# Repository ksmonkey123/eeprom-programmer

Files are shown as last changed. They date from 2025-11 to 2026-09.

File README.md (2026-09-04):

EEPROM Programmer
=================

Arduino-based EEPROM programmer for the AT28C64B (8 KiB) and AT28C256 (32 KiB) EEPROMs.

## Design

The EEPROM programmer consists of 2 parts:
A _Programmer Device_ based consiting of an Arduino Mega 2560 with a daughter-board containing an IC socket for the
EEPROM chips (DIP-28P6).
This _Programmer Device_ interacts with a _Client Program_ on the PC.

## Features

### Software Data Protection

The programmer supports enabling and disabling of the _Software Data Protection_ (Write Lockout) mode on the EEPROM.
This feature can be used as a standalone command (`<cmd> lock` and `<cmd> unlock`), and in combination with other _write
operations_.
It is even possible to unlock an EEPROM, write to it, and lock it again in a single operation.

### Automatic EEPROM size determination

Since the programmer supports 2 different sizes of EEPROMs, the user would have to indicate what type is connected to
the programmer for any given command.
The _Client Program_ is, however, capable of "guessing" the safe EEPROM size for most operations.
In some cases this may lead to additional unnecessary write cycles on smaller chips (which we consider to be a
negligible downside) and potentially increased operation durations.

The following pseudo-C shows the test routine to definitely determine the EEPROM size.
This test can be performed both destructively and non-desctructively.
In all cases the EEPROM _must_ be unlocked beforehand.

```c
bool isLargeChip(bool preserveData) {
  address adr = random(0x0000, 0x2000);
  byte data = read(adr);

  // if there's different data in the higher "blocks", it obviously is a large chip
  if (data != read(adr + 0x2000)) {
    return true;
  }

  // modify low byte, check if high byte changes too
  write(adr, ~data);
  //high byte unchanged means large chip
  bool result = (data == read(adr + 0x2000));

  if (preserveData) {
    write(adr, data);
  }
  return result;
}
```

### Considerate Writes

Unnecessary Write operations are avoided whenever possible. 
This means that the programmer will not write to a byte if the new value is the same as the old one.
This reduces both write times and wear on the EEPROM.

## Operations

### Erase

The `erase` opration writes `0xFF` to every byte of the EEPROM memory.
When an explicit size flag is set, the corresponding deletion logic is performed.
Otherwise, we perform a destructive _size test_ before flashing the EEPROM.

### Dump

The `dump` command reads the entire contents of the EEPROM.
If a size is specified, the output file has the matching size.
If no size is specified, the EEPROM is read as if it were a 32 KiB one.
After that the data is checked.
If all 4 8 KiB blocks match _exactly_, we assume to have read an 8 KiB EEPROM and write the output file with the
matching size.
If there are any differences in the blocks, we save the entire 32 KiB.

### Flash

The `flash` command writes a binary file to the EEPROM.

In cases where no chip size is provided, we perform a _size test_ before flashing the EEPROM.
It is always possible to write a binary file to the EEPROM that is smaller than the capacity of the EEPROM.
In that case, the memory locations not defined by the file remain unchanged.

It is never possible to write a file to an EEPROM that does not have enough capacity.

### Unlock

While the EEPROMs can be unlocked during write operations (erase / flash), a dedicated `unlock` command is also
provided.
Size information is not required for this operation.

### Lock

While the EEPROMs can be locked during write operations (erase / flash), a dedicated `lock` command is also provided.
Size information is not required for this operation.

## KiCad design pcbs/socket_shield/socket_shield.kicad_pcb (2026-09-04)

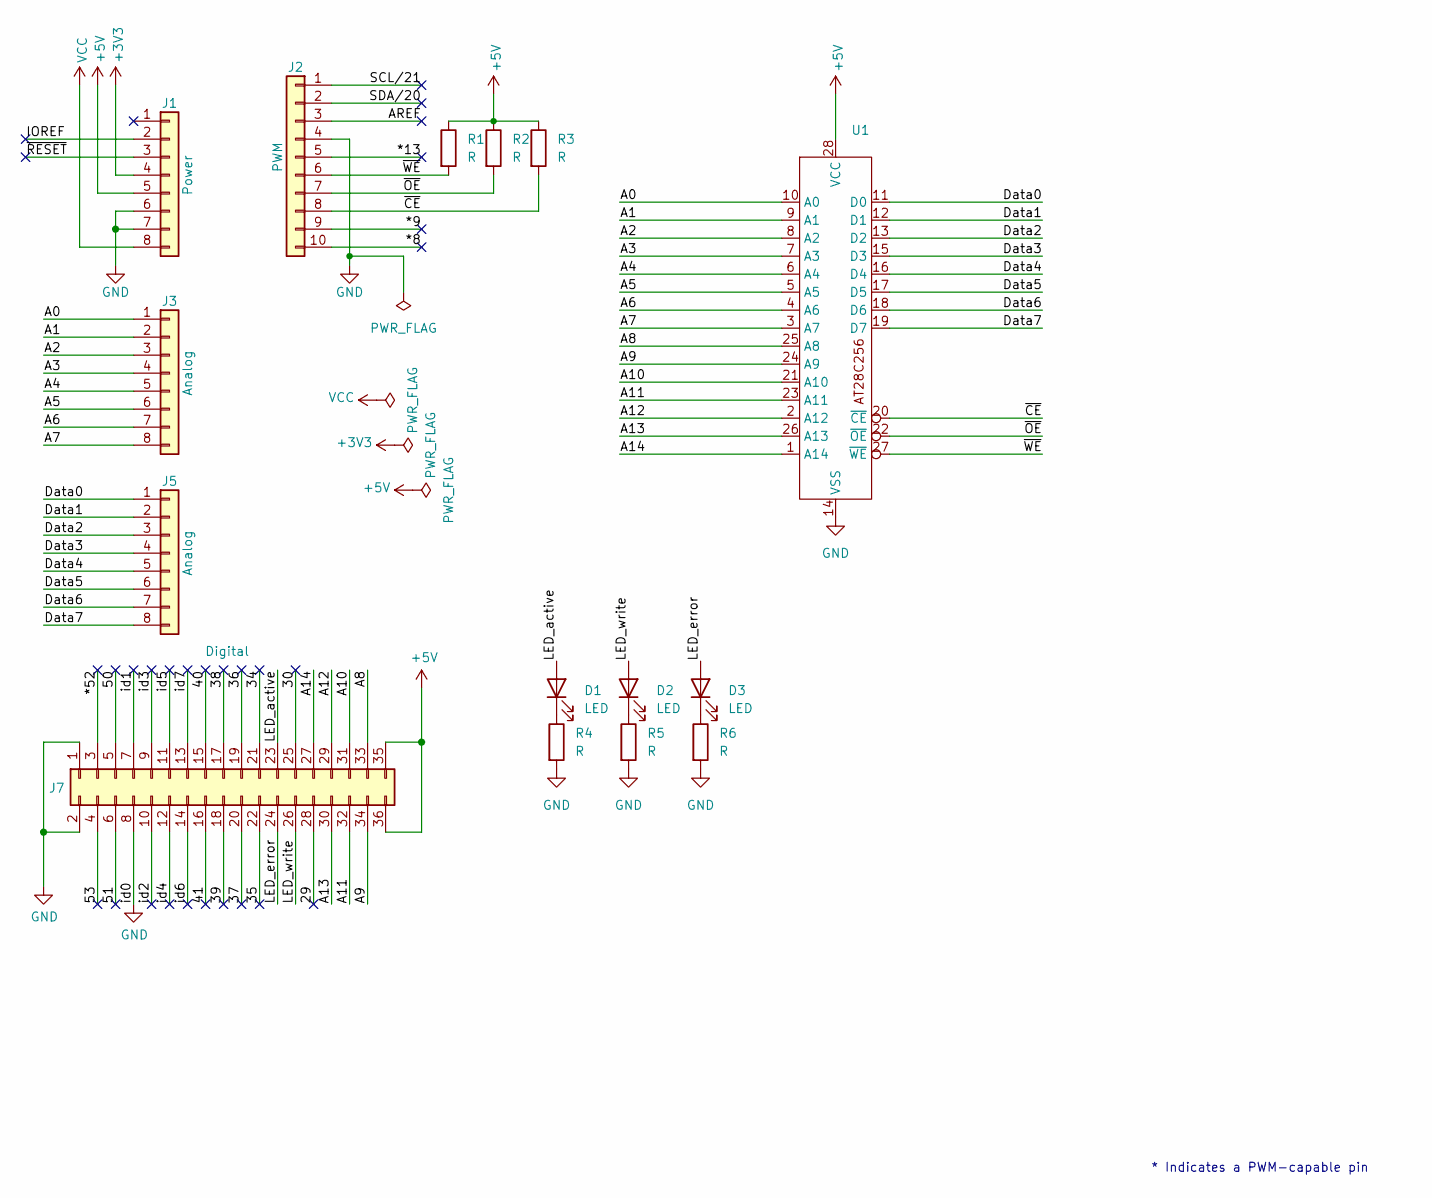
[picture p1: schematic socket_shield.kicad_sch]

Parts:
D1, D2, D3: LED; LED_0603_1608Metric
J1: Power; PinSocket_1x08_P2.54mm_Vertical
J2: PWM; PinSocket_1x10_P2.54mm_Vertical
J3, J5: Analog; PinSocket_1x08_P2.54mm_Vertical
J7: Digital; PinSocket_2x18_P2.54mm_Vertical
R1, R2, R3, R4, R5, R6: R; R_0603_1608Metric
U1: DIP-28_600_ELL

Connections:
+3V3: J1.4
+5V: J1.5, J7.35, J7.36, R1.1, R2.1, R3.1, U1.28 (VCC)
/29: J7.28
/30: J7.25
/34: J7.21
/35: J7.22
/36: J7.19
/37: J7.20
/38: J7.17
/39: J7.18
/40: J7.15
/41: J7.16
/50: J7.5
/51: J7.6
/53: J7.4
/*8: J2.10
/*9: J2.9
/*13: J2.5
/*52: J7.3
/A0: J3.1, U1.10 (A0)
/A1: J3.2, U1.9 (A1)
/A2: J3.3, U1.8 (A2)
/A3: J3.4, U1.7 (A3)
/A4: J3.5, U1.6 (A4)
/A5: J3.6, U1.5 (A5)
/A6: J3.7, U1.4 (A6)
/A7: J3.8, U1.3 (A7)
/A8: J7.33, U1.25 (A8)
/A9: J7.34, U1.24 (A9)
/A10: J7.31, U1.21 (A10)
/A11: J7.32, U1.23 (A11)
/A12: J7.29, U1.2 (A12)
/A13: J7.30, U1.26 (A13)
/A14: J7.27, U1.1 (A14)
/AREF: J2.3
/Data0: J5.1, U1.11 (D0)
/Data1: J5.2, U1.12 (D1)
/Data2: J5.3, U1.13 (D2)
/Data3: J5.4, U1.15 (D3)
/Data4: J5.5, U1.16 (D4)
/Data5: J5.6, U1.17 (D5)
/Data6: J5.7, U1.18 (D6)
/Data7: J5.8, U1.19 (D7)
/IOREF: J1.2
/LED_active: D1.2 (A), J7.23
/LED_error: D3.2 (A), J7.24
/LED_write: D2.2 (A), J7.26
/SCL/21: J2.1
/SDA/20: J2.2
/id1: J7.7
/id2: J7.10
/id3: J7.9
/id4: J7.12
/id5: J7.11
/id6: J7.14
/id7: J7.13
/~CE: J2.8, R3.2, U1.20 (~CE)
/~OE: J2.7, R2.2, U1.22 (~OE)
/~RESET: J1.3
/~WE: J2.6, R1.2, U1.27 (~WE)
GND: J1.6, J1.7, J2.4, J7.1, J7.2, J7.8, R4.2, R5.2, R6.2, U1.14 (VSS)
unnamed: D1.1 (K), R4.1
unnamed: D2.1 (K), R5.1
unnamed: D3.1 (K), R6.1
VCC: J1.8

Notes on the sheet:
* Indicates a PWM-capable pin

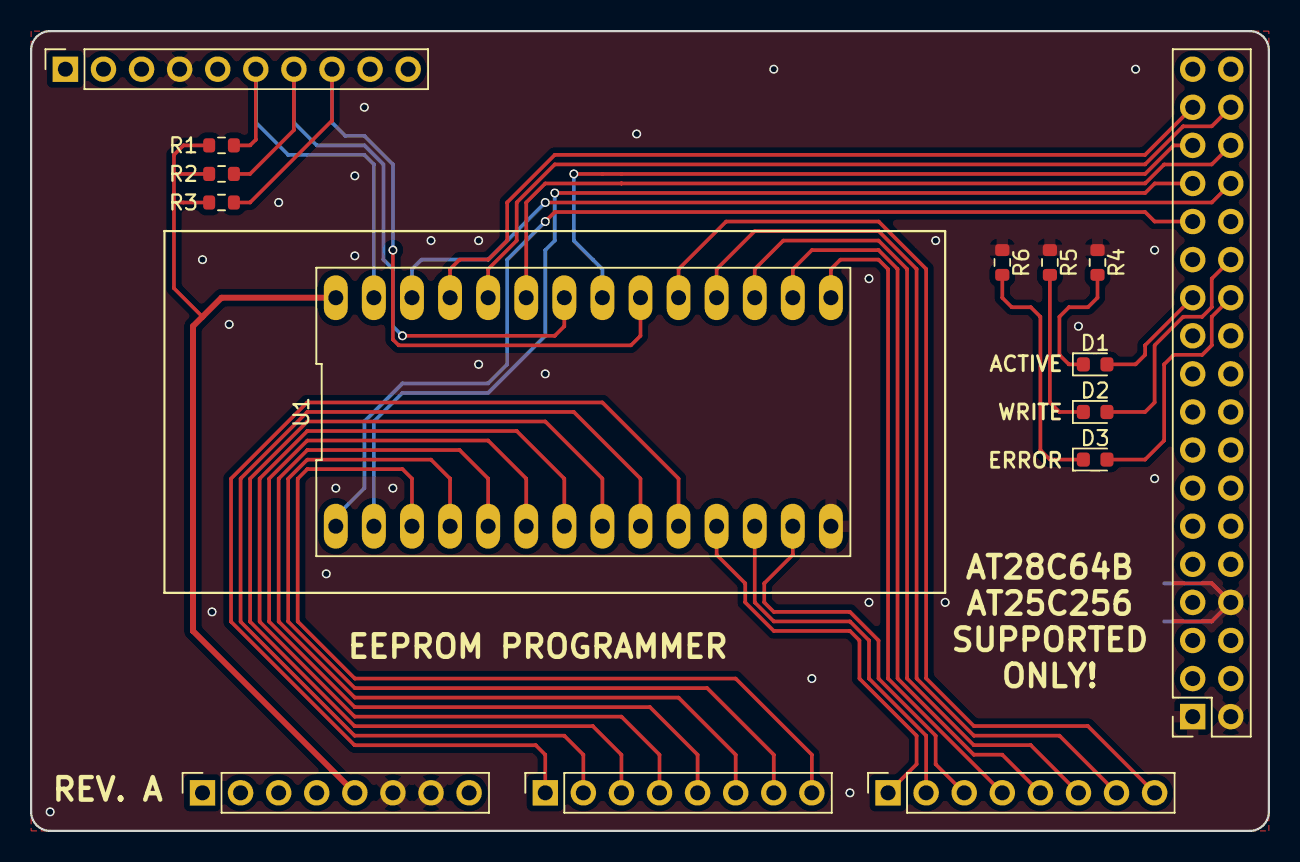
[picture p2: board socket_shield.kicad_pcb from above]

Board: 2 copper layers, 82.6 x 53.3 mm, 15 parts (0 on the bottom side), 34 nets.

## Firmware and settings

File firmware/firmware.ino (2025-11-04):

#define ADDRESS_BUS_O PORTF
#define ADDRESS_BUS_D DDRF

#define PAGE_BUS_O PORTA
#define PAGE_BUS_D DDRA

#define DATA_BUS_O PORTK
#define DATA_BUS_I PINK
#define DATA_BUS_D DDRK

#define CHIP_ENABLE_PIN 10
#define OUTPUT_ENABLE_PIN 11
#define WRITE_ENABLE_PIN 12

#define CHIP_ENABLE_LED 32
#define ERROR_LED 33
#define WRITE_LED 31

void setup() {
  Serial.begin(230400);
  while(!Serial);

  PAGE_BUS_D = 0x7f;
  ADDRESS_BUS_D = 0xff;

  digitalWrite(CHIP_ENABLE_PIN, true);
  digitalWrite(OUTPUT_ENABLE_PIN, true);
  digitalWrite(WRITE_ENABLE_PIN, true);
  digitalWrite(CHIP_ENABLE_LED, true);
  digitalWrite(ERROR_LED, true);
  digitalWrite(WRITE_LED, true);

  pinMode(CHIP_ENABLE_PIN, OUTPUT);
  pinMode(OUTPUT_ENABLE_PIN, OUTPUT);
  pinMode(WRITE_ENABLE_PIN, OUTPUT);
  pinMode(CHIP_ENABLE_LED, OUTPUT);
  pinMode(ERROR_LED, OUTPUT);
  pinMode(WRITE_LED, OUTPUT);
  delay(100);
  digitalWrite(CHIP_ENABLE_LED, false);
  digitalWrite(ERROR_LED, false);
  digitalWrite(WRITE_LED, false);
}

static char buffer[256];
static int buffer_length = 0;

void loop() {
  if (Serial.available() == 0) {
    return;
  }

  // we have data

  char c = Serial.read();
  if (c == 0 || c == '\r') {
    return;
  }

  // process char

  if (c == '\n') {
    // end of command -> process
    processBuffer();
    buffer_length = 0;
    return;
  }

  // fill buffer

  if (buffer_length >= 256) {
    // buffer overflow -> complain and filter
    buffer_length = 0;
    return;
  }

  buffer[buffer_length++] = c;
}

void processBuffer() {
  // TODO
  if (buffer[0] == 'S' && buffer[1] == 'Y' && buffer[2] == 'N' && buffer[3] == '_' && buffer_length == 6) {
    processSync();
  } else if (buffer[0] == 'r') {
    processReadCommand();
  } else if (buffer[0] == 'w') {
    processWriteCommand();
  } else if (buffer[0] == 'p') {
    processPageReadCommand();
  } else if (buffer[0] == 'x') {
    processPageWriteCommand();
  } else {
    digitalWrite(ERROR_LED, true);
    Serial.print("-SYNTAX ERROR: INVALID COMMAND: ");
    for (int i = 0; i < buffer_length; i++) {
      Serial.print(buffer[i]);
    }
    Serial.println();
  }
}

void processSync() {
  for (int i = 0; i < 6; i++) {
    Serial.print(buffer[i]);
  }
  Serial.println();
  digitalWrite(ERROR_LED, false);
}

void processReadCommand() {
  if (buffer_length != 5) {
    digitalWrite(ERROR_LED, true);
    Serial.println("-SYNTAX ERROR: READ COMMAND REQUIRES EXACTLY 4 ADDRESS CHARS");
    return;
  }

  // extract address
  int adrHigh = hexToByte(buffer + 1);
  int adrLow = hexToByte(buffer + 3);

  if (adrHigh == -1 || adrLow == -1) {
    digitalWrite(ERROR_LED, true);
    Serial.println("-SYNTAX ERROR: ADDRESS REQUIRES 4 HEX DIGITS");
    return;
  }

  // assemble address
  int adr = ((adrHigh << 8) & 0xff00) | (adrLow & 0x00ff);

  if (adr < 0 || adr >= 0x8000) {
    digitalWrite(ERROR_LED, true);
    Serial.println("-SYNTAX ERROR: ADDRESS MUST BE IN RANGE 0000..7FFF");
    return;
  }

  // address OK, execute read
  read(adr);
}

void processPageReadCommand() {
  if (buffer_length != 5) {
    digitalWrite(ERROR_LED, true);
    Serial.println("-SYNTAX ERROR: READ COMMAND REQUIRES EXACTLY 4 ADDRESS CHARS");
    return;
  }

  // extract address
  int adrHigh = hexToByte(buffer + 1);
  int adrLow = hexToByte(buffer + 3);

  if (adrHigh == -1 || adrLow == -1) {
    digitalWrite(ERROR_LED, true);
    Serial.println("-SYNTAX ERROR: ADDRESS REQUIRES 4 HEX DIGITS");
    return;
  }

  // assemble address
  int adr = ((adrHigh << 8) & 0xff00) | (adrLow & 0x00ff);

  if (adr < 0 || adr >= 0x8000) {
    digitalWrite(ERROR_LED, true);
    Serial.println("-SYNTAX ERROR: ADDRESS MUST BE IN RANGE 0000..7FFF");
    return;
  }

  if ((adr & 0x003f) > 0) {
    digitalWrite(ERROR_LED, true);
    Serial.println("-SYNTAX ERROR: ADDRESS MUST BE A PAGE START");
    return;
  }

  // address OK, execute read
  pageRead(adr);
}

void processWriteCommand() {
   if (buffer_length != 8) {
    digitalWrite(ERROR_LED, true);
    Serial.println("-SYNTAX ERROR: WRITE COMMAND REQUIRES EXACTLY 4 ADDRESS CHARS, 1 SEPARATOR AND 2 DATA CHARS");
    return;
  }

  // extract address
  int adrHigh = hexToByte(buffer + 1);
  int adrLow = hexToByte(buffer + 3);

  if (adrHigh == -1 || adrLow == -1) {
    digitalWrite(ERROR_LED, true);
    Serial.println("-SYNTAX ERROR: ADDRESS REQUIRES 4 HEX DIGITS");
    return;
  }

  // assemble address
  int adr = ((adrHigh << 8) & 0xff00) | (adrLow & 0x00ff);

  if (adr < 0 || adr >= 0x8000) {
    digitalWrite(ERROR_LED, true);
    Serial.println("-SYNTAX ERROR: ADDRESS MUST BE IN RANGE 0000..7FFF");
    return;
  }

  // address OK
  if (buffer[5] != ':') {
    digitalWrite(ERROR_LED, true);
    Serial.println("-SYNTAX ERROR: WRITE COMMAND NEEDS SEPARATOR AS SIXTH CHAR");
    return;
  }

  int data = hexToByte(buffer + 6);
  if (data == -1) {
    digitalWrite(ERROR_LED, true);
    Serial.println("-SYNTAX ERROR: DATA REQUIRES 2 HEX DIGITS");
    return;
  }

  write(adr, data & 0x00ff);
}

void processPageWriteCommand() {
  if (buffer_length != 134) {
    digitalWrite(ERROR_LED, true);
    Serial.println("-SYNTAX ERROR: WRITE COMMAND REQUIRES EXACTLY 4 ADDRESS CHARS, 1 SEPARATOR AND 128 DATA CHARS");
    return;
  }

  // extract address
  int adrHigh = hexToByte(buffer + 1);
  int adrLow = hexToByte(buffer + 3);

  if (adrHigh == -1 || adrLow == -1) {
    digitalWrite(ERROR_LED, true);
    Serial.println("-SYNTAX ERROR: ADDRESS REQUIRES 4 HEX DIGITS");
    return;
  }

  // assemble address
  int adr = ((adrHigh << 8) & 0xff00) | (adrLow & 0x00ff);

  if (adr < 0 || adr >= 0x8000) {
    digitalWrite(ERROR_LED, true);
    Serial.println("-SYNTAX ERROR: ADDRESS MUST BE IN RANGE 0000..7FFF");
    return;
  }

  if ((adr & 0x003f) > 0) {
    digitalWrite(ERROR_LED, true);
    Serial.println("-SYNTAX ERROR: ADDRESS MUST BE A PAGE START");
    return;
  }

  // address OK
  if (buffer[5] != ':') {
    digitalWrite(ERROR_LED, true);
    Serial.println("-SYNTAX ERROR: WRITE COMMAND NEEDS SEPARATOR AS SIXTH CHAR");
    return;
  }

  // build data buffer
  byte data[64];
  for(int i = 0; i < 64; i++) {
    data[i] = hexToByte(buffer + 6 + (2 * i));
  }

  pageWrite(adr, data);

}

// -------------------------------------------------------
// SERIAL PARSING LOGIC
int hexToByte(char* input) {
  byte high = hexCharToHalfByte(*(input + 0));
  byte low = hexCharToHalfByte(*(input + 1));

  if (high == 255 || low == 255) {
    return -1;
  }

  return ((high << 4) & 0x00f0) | (low & 0x000f);
}

byte hexCharToHalfByte(char input) {
  switch (input) {
    case '0': return 0;
    case '1': return 1;
    case '2': return 2;
    case '3': return 3;
    case '4': return 4;
    case '5': return 5;
    case '6': return 6;
    case '7': return 7;
    case '8': return 8;
    case '9': return 9;
    case 'A': return 10;
    case 'B': return 11;
    case 'C': return 12;
    case 'D': return 13;
    case 'E': return 14;
    case 'F': return 15;
    default: return 255;
  }
}


// -------------------------------------------------------
// CHIP LOGIC

void read(int address) {
  chipEnable(true);
  selectAddress(address);
  digitalWrite(OUTPUT_ENABLE_PIN, false);
  byte readData = DATA_BUS_I;
  digitalWrite(OUTPUT_ENABLE_PIN, true);
  chipEnable(false);

  Serial.write("+");
  if (readData < 16) {
    Serial.print('0');
  }
  Serial.println(readData, HEX);
  digitalWrite(ERROR_LED, false);
}

void pageRead(int address) {
  Serial.write("+");

  chipEnable(true);
  digitalWrite(OUTPUT_ENABLE_PIN, false);
  for (int i = 0; i < 64; i++) {
    selectAddress(address + i);
    delay(1);
    byte readData = DATA_BUS_I;
    
    if (readData < 16) {
      Serial.print('0');
    }
    Serial.print(readData, HEX);
  }
  digitalWrite(OUTPUT_ENABLE_PIN, true);
  chipEnable(false);

  Serial.println();
  digitalWrite(ERROR_LED, false);
}

void write(int address, byte data) {
  chipEnable(true);
  selectAddress(address);
  digitalWrite(WRITE_LED, true);

  DATA_BUS_D = 0xff;
  DATA_BUS_O = data;

  digitalWrite(WRITE_ENABLE_PIN, false);
  digitalWrite(WRITE_ENABLE_PIN, true);
  delay(10);

  DATA_BUS_D = 0x00;
  DATA_BUS_O = 0x00;
  
  digitalWrite(WRITE_LED, false);
  
  digitalWrite(OUTPUT_ENABLE_PIN, false);
  byte readData = DATA_BUS_I;
  digitalWrite(OUTPUT_ENABLE_PIN, true);
  chipEnable(false);

  if (readData == data) {
    digitalWrite(ERROR_LED, false);
    Serial.println("+");
  } else {
    digitalWrite(ERROR_LED, true);
    Serial.print("-WRITE CHECK ERROR: ADDRESS ");
    Serial.print(address, HEX);
    Serial.print(" EXPECTED ");
    Serial.print(data, HEX);
    Serial.print(" BUT READ ");
    Serial.println(readData, HEX);
  }
}

void pageWrite(int address, byte* data) {
  chipEnable(true);
  digitalWrite(WRITE_LED, true);

  DATA_BUS_D = 0xff;
  for (int i = 0; i < 64; i++) {
    selectAddress(address + i);
    DATA_BUS_O = *(data + i);
    digitalWrite(WRITE_ENABLE_PIN, false);
    digitalWrite(WRITE_ENABLE_PIN, true);
  }
  delay(10);

  DATA_BUS_O = 0x00;
  
  digitalWrite(WRITE_LED, false);
  DATA_BUS_D = 0x00;

  // verify data
  digitalWrite(OUTPUT_ENABLE_PIN, false);

  for (int i = 0; i < 64; i++) {
    selectAddress(address + i);
    delay(1);
    byte readData = DATA_BUS_I;
    
    if (readData != *(data + i)) {
      digitalWrite(ERROR_LED, true);
      Serial.print("-WRITE CHECK ERROR: ADDRESS ");
      Serial.print(address + i, HEX);
      Serial.print(" EXPECTED ");
      Serial.print(*(data + i), HEX);
      Serial.print(" BUT READ ");
      Serial.println(readData, HEX);
      digitalWrite(OUTPUT_ENABLE_PIN, true);
      chipEnable(false);
      return;
    }
  }
  Serial.println("+");
  digitalWrite(OUTPUT_ENABLE_PIN, true);
  chipEnable(false);  
}

void selectAddress(int addr) {
  PAGE_BUS_O = (addr >> 8) & 0x007f;
  ADDRESS_BUS_O = addr & 0x00ff;
}

void chipEnable(bool state) {
  digitalWrite(CHIP_ENABLE_PIN, !state);
  digitalWrite(CHIP_ENABLE_LED, state);
}

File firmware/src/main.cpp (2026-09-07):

#include "../include/command_executor.h"
#include "common.h"
#include "communications.h"

#define ADDRESS_BUS_O PORTF
#define ADDRESS_BUS_D DDRF

#define PAGE_BUS_O PORTA
#define PAGE_BUS_D DDRA

#define DATA_BUS_O PORTK
#define DATA_BUS_I PINK
#define DATA_BUS_D DDRK

void setup() {
    // no special init
}

__attribute__((noreturn)) void loop() {
    static char buffer[134];

    const Communications comms(Serial);
    Print &output = comms.getOutput();
    const CommandExecutor cmd(output);

    while (true) {
        const int length = comms.receiveNextCommand(buffer, 134);

        char const *args = buffer + 1;
        const int len = length - 1;

        switch (buffer[0]) {
            case 'l':
                cmd.lock(len);
                break;
            case 'u':
                cmd.unlock(len);
                break;
            case 'r':
                cmd.pageRead(args, len);
                break;
            case 'w':
                cmd.pageWrite(args, len);
                break;
            case 'i':
                cmd.identifyType(len);
                break;
            default:
                output.print(F("-UNSUPPORTED OR MALFORMED COMMAND: "));
                for (int i = 0; i < length; i++) {
                    output.print(buffer[i]);
                }
                output.println();
                break;
        }
    }
}

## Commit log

2025-02-17 update firmware
    page commands were still missing in the committed version...
    [firmware.ino]
2025-11-04 arduino shield PCB
    [socket_shield.kicad_pcb, socket_shield.kicad_sch]
2025-11-07 add gitignore for pcb projects
2025-11-07 root directory for all pcbs. there will be more than just the socket shield, so it makes sense to bundle them.
    [socket_shield.kicad_pcb, socket_shield.kicad_sch]
2025-11-21 increase hole sizes for socket
    [socket_shield.kicad_pcb, socket_shield.kicad_sch]
2025-11-21 add id pins at designate the socket shield as id 0x01
    [socket_shield.kicad_pcb, socket_shield.kicad_sch]
2026-09-01 drop live shell mode. no real use-case besides testing the firmware, which can be done manually anyways...
2026-09-02 replace serial integration. move to event-based input processing
    [Main.kt]
2026-09-02 more testing, more robust implementation of com device
2026-09-02 log device ID on on connection
2026-09-03 firmware optimization: only actually write data if it needs to change. In the best case this "spares" us a complete write cycle if an entire page is unchanged by the write command. (e.g. erasing an a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
2026-09-04 move PCB
    [socket_shield.kicad_pcb, socket_shield.kicad_sch]
